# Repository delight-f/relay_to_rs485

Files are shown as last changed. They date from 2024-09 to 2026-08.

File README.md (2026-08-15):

# Relay to RS485

Mirror relay states over an RS-485 bus using the Modbus protocol.






## Overview

An ESP32-S2 reads up to five zero-voltage relay contacts and mirrors their
state onto an RS-485 bus as Modbus coils, so an external master can switch
the corresponding output relays. Developed for amateur radio: retrofitting
an existing proprietary system to allow coil switching — moving antenna
directors or changing bands. Designed to work with commonly available
RS-485 relay boards (AliExpress, eBay, etc.).

The repository contains both the firmware and the KiCad PCB design.

## Repository layout

```
.
├── relay_to_rs485/          # Arduino sketch (firmware)
│   ├── relay_to_rs485.ino   # entry point, setup()/loop()
│   └── debounce.h           # host-testable input debouncer
├── test/
│   └── test_debounce.cpp    # host unit tests for the debouncer
├── Hardware/
│   └── relay_to_rs485/      # KiCad 7 project + gerbers (REV_B)
├── Makefile                 # build/test entry point (arduino-cli)
├── sketch.yaml              # arduino-cli sketch configuration
└── .github/workflows/ci.yml # host tests + firmware build
```

## Hardware

The PCB has eight input pins hardwired; the current firmware uses five,
leaving room for future relay expansion. It was designed around an 8-relay
board.

- KiCad project: [`Hardware/relay_to_rs485/`](Hardware/relay_to_rs485/)
- Manufacturing files (REV_B gerbers):
  [`Hardware/relay_to_rs485/gerbers/`](Hardware/relay_to_rs485/gerbers/)

## Firmware

- Board: LOLIN S2 Mini (ESP32-S2)
- Framework: Arduino, built with [arduino-cli](https://arduino.github.io/arduino-cli/)
- Modbus: [ModbusMaster](https://github.com/4-20ma/ModbusMaster) 2.0.1
- Input filtering: ESP32 hardware glitch filter + software debounce
  (`debounce.h`, host-testable)

### Prerequisites

- [arduino-cli](https://arduino.github.io/arduino-cli/latest/installation/) ≥ 1.0
- ESP32 core and ModbusMaster library:

```bash
arduino-cli config add board_manager.additional_urls \
  https://espressif.github.io/arduino-esp32/package_esp32_index.json
arduino-cli core update-index
arduino-cli core install esp32:esp32
arduino-cli lib install ModbusMaster@2.0.1
```

### Build and flash

```bash
git clone git@github.com:delight-f/relay_to_rs485.git
cd relay_to_rs485
make            # build firmware
make upload     # build and flash over USB
```

Or without make:

```bash
arduino-cli compile --fqbn esp32:esp32:lolin_s2_mini relay_to_rs485
arduino-cli compile --fqbn esp32:esp32:lolin_s2_mini relay_to_rs485 --upload
```

### Test

The debounce logic is pure C++ and unit-tested on the host — no Arduino
required:

```bash
make test
```

### Configuration

Pin assignments, Modbus slave ID, and channel count are named `constexpr`
constants at the top of `relay_to_rs485/relay_to_rs485.ino`. Adjust these
to match your wiring before flashing.

| Constant | Default | Meaning |
| --- | --- | --- |
| `kModbusSlaveId` | `255` | Modbus slave ID |
| `kModbusBaud` | `9600` | RS-485 baud rate (8E1) |
| `kModbusRxPin` / `kModbusTxPin` | `31` / `35` | RS-485 UART pins |
| `kNumChannels` | `5` | Number of input/coil pairs |
| `kInputPins` | `15, 17, 18, 19, 20` | Input pins (active-low, pull-up) |
| `kCoilAddresses` | `0x0000…0x0004` | Modbus coil addresses |
| `kPollIntervalMs` | `50` | Loop poll interval |
| `kDebounceMs` | `30` | Software debounce window |
| `kMaxWriteRetries` | `3` | Modbus write retry count |

Inputs are active-low: pull-up means HIGH = relay not active (`false`),
LOW = relay active (`true`).

## Versioning

This project uses [SemVer](https://semver.org/).

## Contributing

Issues and pull requests are welcome. Please open an issue to discuss
significant changes before submitting a PR.

## License

Creative Commons Attribution-ShareAlike 4.0 International License.
See [LICENSE](./LICENSE) for details.

## Acknowledgments

- [ModbusMaster](https://github.com/4-20ma/ModbusMaster) library
- [arduino-cli](https://arduino.github.io/arduino-cli/) toolchain

## Authors

- **de_light** — initial work

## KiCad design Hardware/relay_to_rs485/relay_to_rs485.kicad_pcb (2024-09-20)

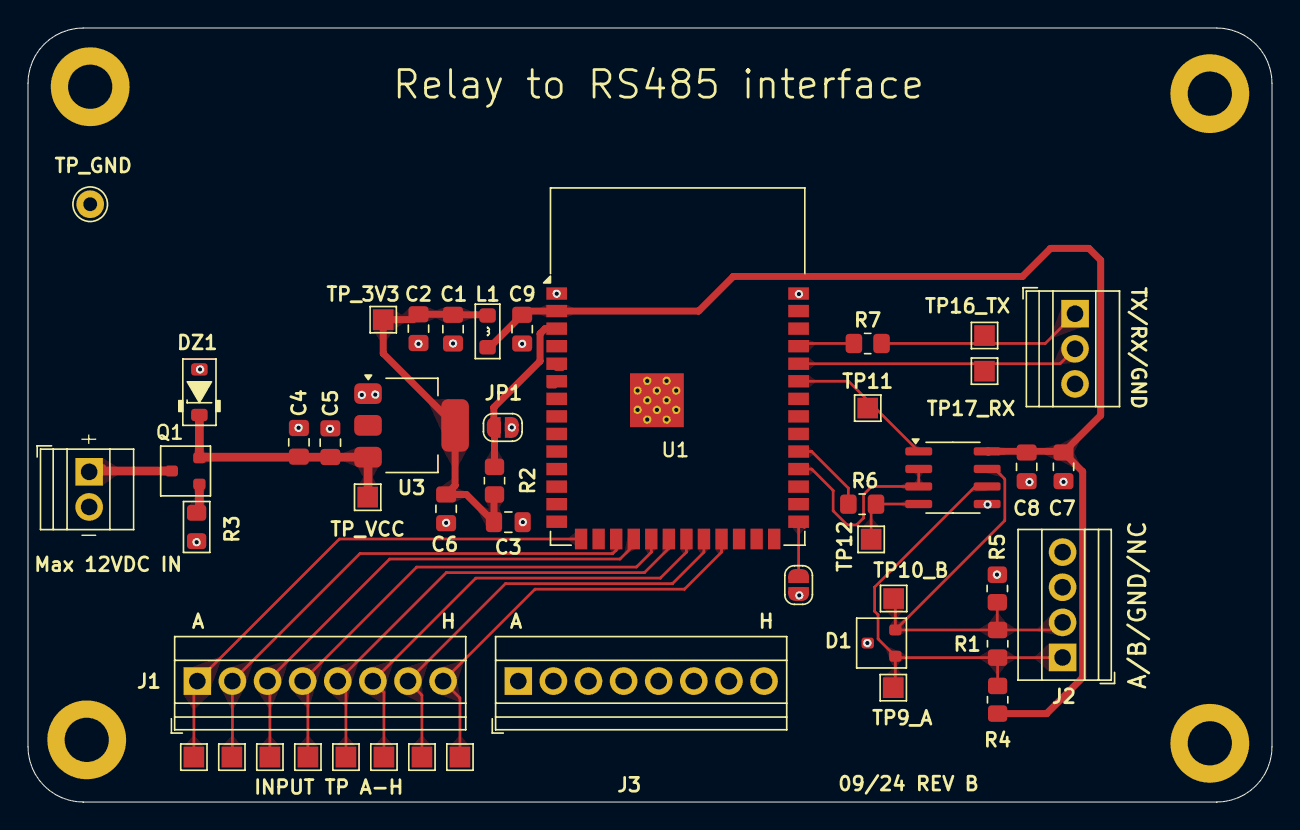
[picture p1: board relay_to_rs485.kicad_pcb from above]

Board: 2 copper layers, 90.0 x 56.0 mm, 47 parts (0 on the bottom side), 24 nets.

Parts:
C1, C3, C5, C8, C9: 0.1uF; C_0805_2012Metric_Pad1.18x1.45mm_HandSolder
C2, C4, C7: 1uF; C_0805_2012Metric_Pad1.18x1.45mm_HandSolder
C6: 22uF; C_0805_2012Metric_Pad1.18x1.45mm_HandSolder
D1: SM712 TVS; SOT-23
DZ1: 7.5 or 8.2; D_SOD-123_Zener
J1: Relay Inputs A to E connected; TerminalBlock_Xinya_XY308-2.54-8P_1x08_P2.54mm_Horizontal
J2: RS485 Output Screw Terminal; TerminalBlock_Xinya_XY308-2.54-4P_1x04_P2.54mm_Horizontal
J3: Screw_Terminal_InputGrounds; TerminalBlock_Xinya_XY308-2.54-8P_1x08_P2.54mm_Horizontal
J4: Max 12VDC IN; TerminalBlock_Xinya_XY308-2.54-2P_1x02_P2.54mm_Horizontal
J5: UART OUT; TerminalBlock_Xinya_XY308-2.54-3P_1x03_P2.54mm_Horizontal
JP1: EN_RST; SolderJumper-2_P1.3mm_Open_RoundedPad1.0x1.5mm
JP2: PROG; SolderJumper-2_P1.3mm_Open_RoundedPad1.0x1.5mm
L1: 2.2nH; L_0805_2012Metric_Pad1.05x1.20mm_HandSolder
Q1: IRLML6401; SOT-23
R1: 100R; R_0805_2012Metric_Pad1.20x1.40mm_HandSolder
R2: 4.7k; R_0805_2012Metric_Pad1.20x1.40mm_HandSolder
R3: 100R; R_0805_2012Metric_Pad1.15x1.40mm_HandSolder
R4, R5: 330R; R_0805_2012Metric_Pad1.20x1.40mm_HandSolder
R6, R7: 470R; R_0805_2012Metric_Pad1.20x1.40mm_HandSolder
TP1_A1, TP2_B1, TP3_C1, TP4_D1, TP5_E1, TP6_F1, TP7_G1, TP9_A, TP10_B, TP11, TP12, TP13_3V3, TP15_VCC1, TP16_TX, TP17_RX: TestPoint_Pad_1.5x1.5mm
TP8_H1: TestPoint_Probe; TestPoint_Pad_1.5x1.5mm
TP14_GND1: Pin_D1.0mm_L10.0mm
U1: ESP32-S3-WROOM-1
U2: MAX485E; SOIC-8_3.9x4.9mm_P1.27mm
U3: SMX1117MP-3.3; SOT-223-3_TabPin2

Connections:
+3V3: C1.1, C2.1, C3.1, C6.1, C7.1, C8.1, C9.1, L1.1, L1.2, R2.1, R4.1, TP13_3V3.1, U1.2 (3V3), U2.8 (VCC), U3.2 (VO)
/A+: D1.1 (A1), J2.1, R1.1, R4.2, TP9_A.1, U2.6 (A)
/B-: D1.2 (A2), J2.2, R1.2, R5.1, TP10_B.1, U2.7 (B)
/InputA: J1.1, TP1_A1.1, U1.15 (IO3)
/InputB: J1.2, TP2_B1.1, U1.17 (IO9)
/InputC: J1.3, TP3_C1.1, U1.18 (IO10)
/InputD: J1.4, TP4_D1.1, U1.19 (IO11)
/InputE: J1.5, TP5_E1.1, U1.20 (IO12)
/InputF: J1.6, TP6_F1.1, U1.21 (IO13)
/InputG: J1.7, TP7_G1.1, U1.22 (IO14)
/InputH: J1.8, TP8_H1.1, U1.23 (IO21)
/RX: J5.2, TP17_RX.1, U1.36 (RXD0)
/TX: J5.1, R7.1, TP16_TX.1
GND: C1.2, C2.2, C3.2, C4.2, C5.2, C6.2, C7.2, C8.2, C9.2, D1.3 (Com), DZ1.2 (A), J2.3, J3.1, J3.2, J3.3, J3.4, J3.5, J3.6, J3.7, J3.8, J4.2, J5.3, JP1.2 (B), JP2.2 (B), R3.2, R5.2, TP14_GND1.1, U1.1 (GND), U1.40 (GND), U1.41 (GND), U2.5 (GND), U3.1 (GND)
unnamed: JP1.1 (A), R2.2, U1.3 (EN)
unnamed: JP2.1 (A), U1.27 (IO0)
unnamed: J4.1, Q1.3 (D)
unnamed: Q1.1 (G), R3.1
unnamed: U1.30 (IO37), U2.2 (~RE), U2.3 (DE)
unnamed: R6.2, U1.31 (IO38)
unnamed: TP11.1, U1.35 (IO42), U2.1 (RO)
unnamed: R7.2, U1.37 (TXD0)
unnamed: R6.1, TP12.1, U2.4 (DI)
VCC: C4.1, C5.1, DZ1.1 (K), Q1.2 (S), TP15_VCC1.1, U3.3 (VI)

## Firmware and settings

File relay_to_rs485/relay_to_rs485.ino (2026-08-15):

/*
 * Relay-to-RS485 bridge firmware (ESP32-S2 / lolin_s2_mini).
 *
 * Reads up to `NUM_CHANNELS` active-low digital inputs (relay contacts)
 * and mirrors their debounced state onto a Modbus RTU RS-485 bus as
 * coils, so an external master can switch the corresponding output
 * relays. Inputs are filtered by both the ESP32 hardware glitch filter
 * and a software debounce.
 *
 * SPDX-License-Identifier: CC-BY-SA-4.0
 */

#include <Arduino.h>
#include <ModbusMaster.h>
#include <driver/gpio_filter.h>

#include "debounce.h"

// ---------------------------------------------------------------------------
// Configuration
// ---------------------------------------------------------------------------

// Modbus slave ID for the relay board.
constexpr uint8_t kModbusSlaveId = 255;

// RS-485 UART settings (the board's transceiver is wired to these pins).
constexpr unsigned long kModbusBaud = 9600;
constexpr uint8_t kModbusRxPin = 31;
constexpr uint8_t kModbusTxPin = 35;

// Debug serial baud.
constexpr unsigned long kDebugBaud = 115200;

// Number of input/coil pairs.
constexpr size_t kNumChannels = 5;

// Digital input pins wired to the input relays.
constexpr uint8_t kInputPins[kNumChannels] = {15, 17, 18, 19, 20};

// Modbus coil addresses corresponding to each input pin.
constexpr uint16_t kCoilAddresses[kNumChannels] = {0x0000, 0x0001, 0x0002,
                                                   0x0003, 0x0004};

// Poll interval — paces the loop so the RS-485 bus is not hammered and
// inputs get a stable read.
constexpr unsigned long kPollIntervalMs = 50;

// Software debounce: input must read the same value for this long before
// it is accepted as a real state change (hardware glitch filter is
// independent of and complements this).
constexpr unsigned long kDebounceMs = 30;

// Retry attempts for a failed Modbus write.
constexpr uint8_t kMaxWriteRetries = 3;

// ---------------------------------------------------------------------------
// State
// ---------------------------------------------------------------------------

ModbusMaster node;
relay::Debounce debouncers[kNumChannels];

// Last value actually written to Modbus for each channel.
bool lastSentState[kNumChannels] = {};

// ---------------------------------------------------------------------------
// Helpers
// ---------------------------------------------------------------------------

// Reads the pin and applies the active-low mapping: pull-up means HIGH =
// relay not active (false), LOW = relay active (true).
bool readMappedInput(uint8_t pin) { return digitalRead(pin) == LOW; }

// Writes a coil with retries. Returns true on success.
bool writeCoilWithRetry(uint16_t address, bool value, size_t channelIndex) {
  for (uint8_t attempt = 1; attempt <= kMaxWriteRetries; ++attempt) {
    const uint8_t result = node.writeSingleCoil(address, value);
    if (result == node.ku8MBSuccess) {
      return true;
    }
    Serial.printf("Channel %u: coil 0x%04X write failed (code 0x%02X), "
                  "attempt %u/%u\n",
                  channelIndex, address, result, attempt, kMaxWriteRetries);
    delay(10);  // brief pause before retrying, avoids re-flooding a busy bus
  }
  Serial.printf("Channel %u: coil 0x%04X write abandoned after %u attempts\n",
                channelIndex, address, kMaxWriteRetries);
  return false;
}

// ---------------------------------------------------------------------------
// Setup
// ---------------------------------------------------------------------------

void setup() {
  Serial.begin(kDebugBaud);

  Serial1.begin(kModbusBaud, SERIAL_8E1, kModbusRxPin, kModbusTxPin);
  node.begin(kModbusSlaveId, Serial1);

  for (size_t i = 0; i < kNumChannels; ++i) {
    pinMode(kInputPins[i], INPUT_PULLUP);
    debouncers[i] = relay::Debounce(kDebounceMs);
  }

  // Configure and enable a hardware glitch filter on each input pin.
  // Each pin needs its own config struct and its own handle — the handle
  // is populated by gpio_new_pin_glitch_filter, not declared empty and
  // enabled directly. Handles are intentionally leaked: they must stay
  // alive for the life of the program.
  for (size_t i = 0; i < kNumChannels; ++i) {
    const gpio_pin_glitch_filter_config_t filterConfig = {
        .clk_src = GLITCH_FILTER_CLK_SRC_DEFAULT,
        .gpio_num = static_cast<gpio_num_t>(kInputPins[i]),
    };

    gpio_glitch_filter_handle_t filterHandle = nullptr;
    esp_err_t err = gpio_new_pin_glitch_filter(&filterConfig, &filterHandle);
    if (err != ESP_OK) {
      Serial.printf("Pin %u: failed to create glitch filter (err %d)\n",
                    kInputPins[i], err);
      continue;
    }

    err = gpio_glitch_filter_enable(filterHandle);
    if (err != ESP_OK) {
      Serial.printf("Pin %u: failed to enable glitch filter (err %d)\n",
                    kInputPins[i], err);
    }
  }

  // Prime state so the first loop iteration only sends coils that genuinely
  // need setting, rather than assuming a stale default. reset() trusts the
  // boot reading immediately, so an input that is already active at power-on
  // is not reported as a spurious change.
  for (size_t i = 0; i < kNumChannels; ++i) {
    const bool initial = readMappedInput(kInputPins[i]);
    debouncers[i].reset(initial, millis());

    if (writeCoilWithRetry(kCoilAddresses[i], initial, i)) {
      lastSentState[i] = initial;
    } else {
      // Initial write failed: force a resend attempt on the first loop pass
      // by marking the sent state as unknown/opposite.
      lastSentState[i] = !initial;
    }
  }
}

// ---------------------------------------------------------------------------
// Loop
// ---------------------------------------------------------------------------

void loop() {
  static unsigned long lastPollTime = 0;
  const unsigned long now = millis();

  if (now - lastPollTime < kPollIntervalMs) {
    return;  // not time to poll yet — keeps bus traffic paced
  }
  lastPollTime = now;

  for (size_t i = 0; i < kNumChannels; ++i) {
    const bool raw = readMappedInput(kInputPins[i]);
    const bool stable = debouncers[i].update(raw, now);

    // Debounced value differs from what was last sent — send it.
    if (stable != lastSentState[i]) {
      if (writeCoilWithRetry(kCoilAddresses[i], stable, i)) {
        lastSentState[i] = stable;
      }
      // on failure, lastSentState is left unchanged so it retries next poll
    }
  }
}

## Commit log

2024-09-03 Initial upload
    Initial upload - preproduction draft of REV A
    [relay_to_rs485.kicad_pcb, relay_to_rs485.kicad_sch]
2024-09-03 Minor rotation of J2 labelling on schematic
    [relay_to_rs485.kicad_sch]
2024-09-06 various edits
    [relay_to_rs485-B_Cu.gbl, relay_to_rs485-B_Mask.gbs, relay_to_rs485-B_Paste.gbp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]
2024-09-06 board updates
    [relay_to_rs485-B_Cu.gbl, relay_to_rs485-B_Mask.gbs, relay_to_rs485-B_Paste.gbp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]
2024-09-08 Changed decoupling resistor values from 100uF to 1uF
    Too high capacitance
    Also changed silkscreen for R1 to make clear terminating resistor
    [relay_to_rs485.kicad_pcb, relay_to_rs485.kicad_sch]
2024-09-09 Change of DC polarity marking on PCB
    [relay_to_rs485.kicad_pcb, relay_to_rs485.kicad_sch]
2024-09-10 Revision B of Board (2.0.0)
    Add:
    1. LC filter on 3.3V input
    2. Change trace widths to 20mil for 3.3V and 25mil for VCC as per Espressif documentation
    3. Add-in 470R UART Tx resistors to suppress 80MHz harmonics
    4. Rerouting of components around MAX3485 chip
    5. Change value of R2 EN pullup resistor to 4.7k
    [relay_to_rs485.kicad_pcb, relay_to_rs485.kicad_sch]
2024-09-10 Minor change
    [relay_to_rs485.kicad_pcb]
2024-09-10 Forgot TP_GND
    [relay_to_rs485.kicad_pcb]
2024-09-10 Fiddling around with TP_GND position
    [relay_to_rs485.kicad_pcb]
2024-09-19 v2.0.1
    Board layout improvements
    [relay_to_rs485.kicad_pcb]
2024-09-19 Corrected reverse D-S pins for IRLM6401 Q1
    [relay_to_rs485.kicad_pcb]
2024-09-19 More reworking of board
    Addition of ZD1, MOSFET RP protection diode, reconfig of JP1 etc
    [relay_to_rs485.kicad_pcb]
2024-09-20 More changes
    [relay_to_rs485-B_Cu.gbl, relay_to_rs485-B_Mask.gbs, relay_to_rs485-B_Paste.gbp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]
2024-09-20 Moved writing mark to back silkscreen
    [relay_to_rs485-B_Cu.gbl, relay_to_rs485-B_Mask.gbs, relay_to_rs485-B_Paste.gbp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]
2024-09-27 Pin changes for ESP32-S3-WROOM board
    Changes from LOLIN S2 Mini prototyping board pins to ESP-S3-WROOM in preparation for production
    Note only pins first five pins are connected, others are left for redundancy.
2026-08-15 fix: correct glitch filter init and harden Modbus relay polling
    - Fix uninitialised gpio_glitch_filter_handle_t causing undefined
    behaviour; handle is now populated via gpio_new_pin_glitch_filter()
    before being enabled, with a per-pin config struct
    - Add retry and error logging to writeSingleCoil() calls, previously
    discarded silently
    - Add poll interval (50ms) to stop continuous bus flooding
    - Add debounce (30ms) on digital inputs before treating a change as real
    - Only write coils when debounced state differs from last sent value,
    reducing unnecessary RS-485 traffic
    - Replace magic numbers (slave ID, UART pins, baud rates, retry count)
    with named constants
2026-08-15 docs: rewrite README to current documentation
    Remove redundant "Built With" section
    - Restructure into Overview/Hardware/Firmware sections
    - Add prerequisites and copy-pasteable build/flash quickstart
    - Add configuration section pointing to firmware constants
    - Add Contributing section
    - Add license/platform/framework badges
    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
2026-08-15 refactor: modernise for arduino-cli, drop PlatformIO, add tests
    Restructure the repo to a PlatformIO-agnostic layout and update
    the toolchain to mid-2026 standards:
    - Move firmware to relay_to_rs485/ sketch dir (arduino-cli convention);
    remove PlatformIO scaffolding (platformio.ini, .vscode, placeholder
    READMEs, Desktop.code-workspace)
    - Delete vendored esp-idf driver/gpio_filter.h (stale copy with stray
    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
2026-08-15 fix: trust boot input state, set explicit glitch filter clock
    Two firmware correctness fixes:
    - Debounce: add reset() to seed the initial state without a debounce
    delay. Previously setup() used update(), so an input already active
    at power-on was reported as false for the first 30ms, causing a
    spurious coil write (false then true) on every boot.
    - Glitch filter: set .clk_src = GLITCH_FILTER_CLK_SRC_DEFAULT
    explicitly instead of relying on the driver's implicit zero-fallback,
    documenting the intended clock source.
    Add host tests covering reset() boot-priming.
    [relay_to_rs485.ino]

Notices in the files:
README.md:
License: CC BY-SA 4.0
